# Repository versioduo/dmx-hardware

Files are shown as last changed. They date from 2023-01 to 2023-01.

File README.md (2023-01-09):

# dmx-hardware

🚥 MIDI to DMX Bridge

## Board

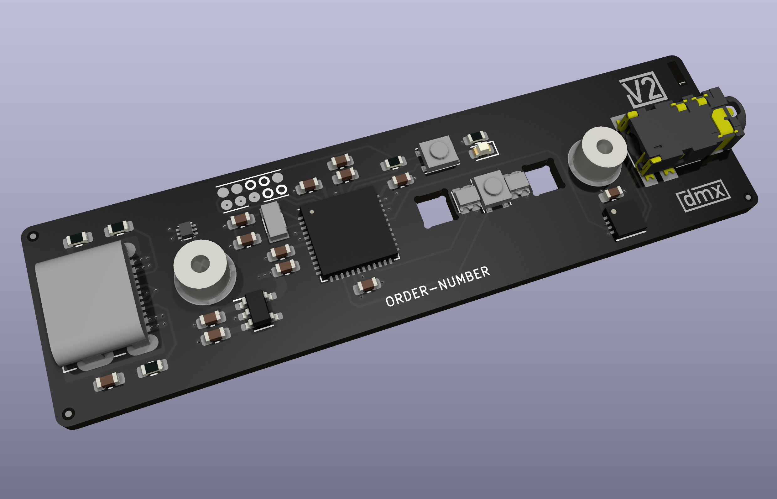
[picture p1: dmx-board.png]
board


## Schematic

[PDF](dmx.pdf)

## Bill Of Materials

[Interactive BOM](https://htmlpreview.github.io/?https://github.com/versioduo/dmx-hardware/main/dmx-bom.html)

## Software

Firmware Repository

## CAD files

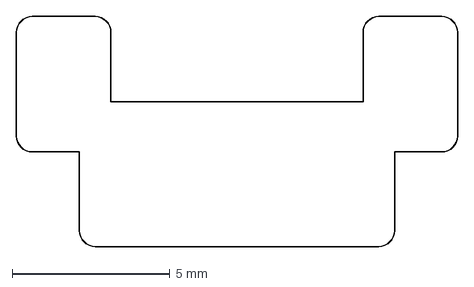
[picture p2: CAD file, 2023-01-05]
button-laser.dxf
14.0 x 7.30 mm

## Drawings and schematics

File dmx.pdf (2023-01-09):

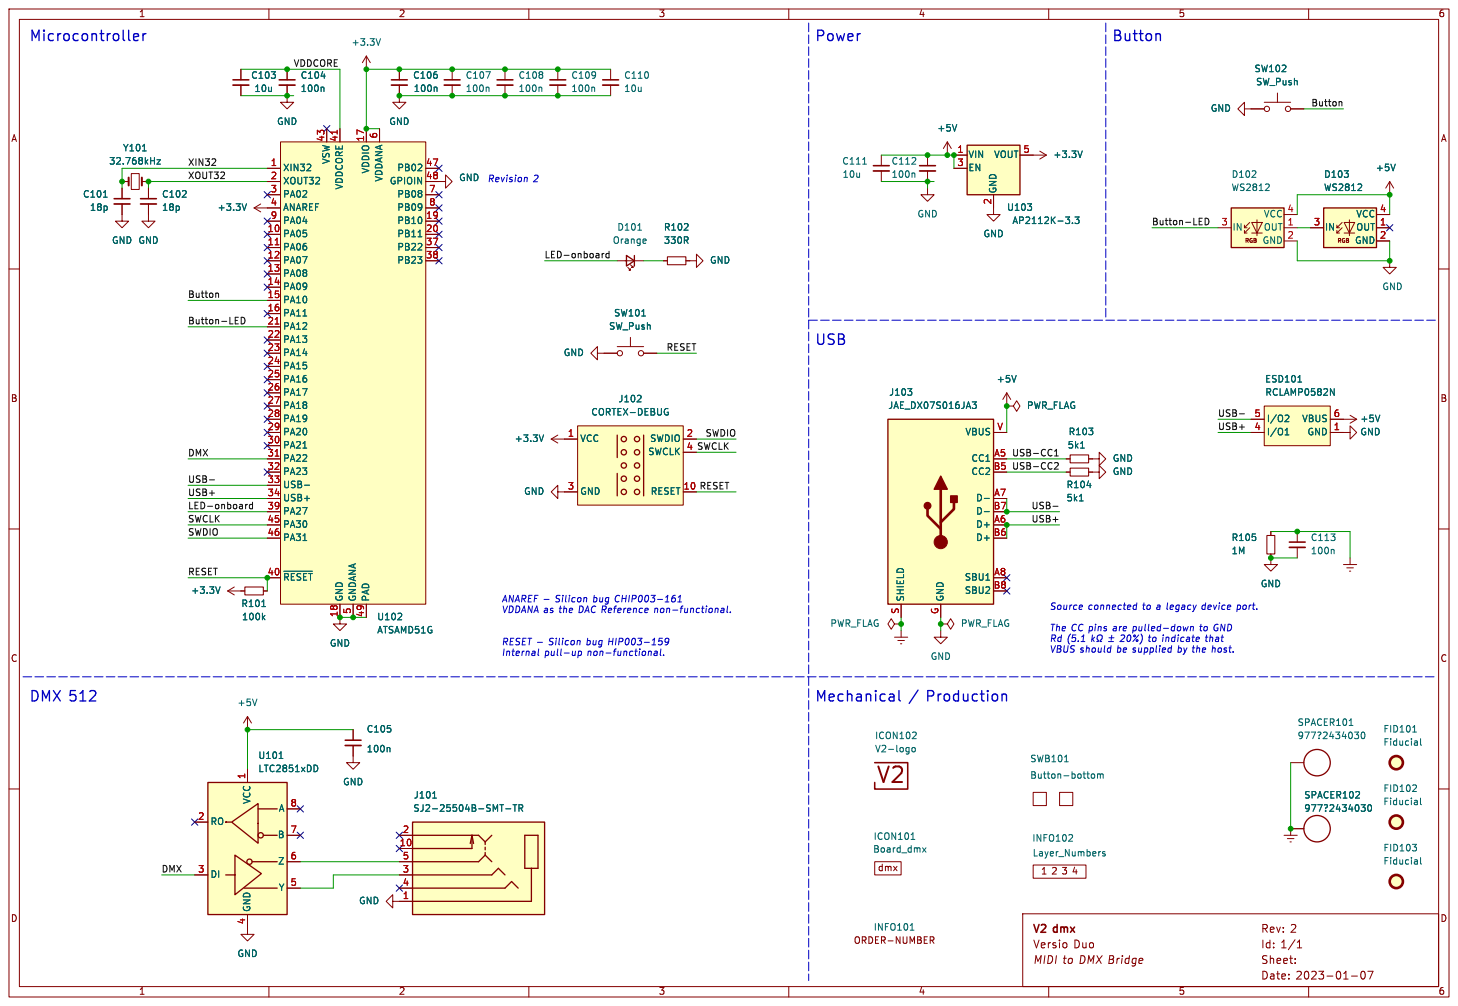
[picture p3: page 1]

The CC pins are pulled-down to GND
VBUS should be supplied by the host.

Internal pull-up non-functional.

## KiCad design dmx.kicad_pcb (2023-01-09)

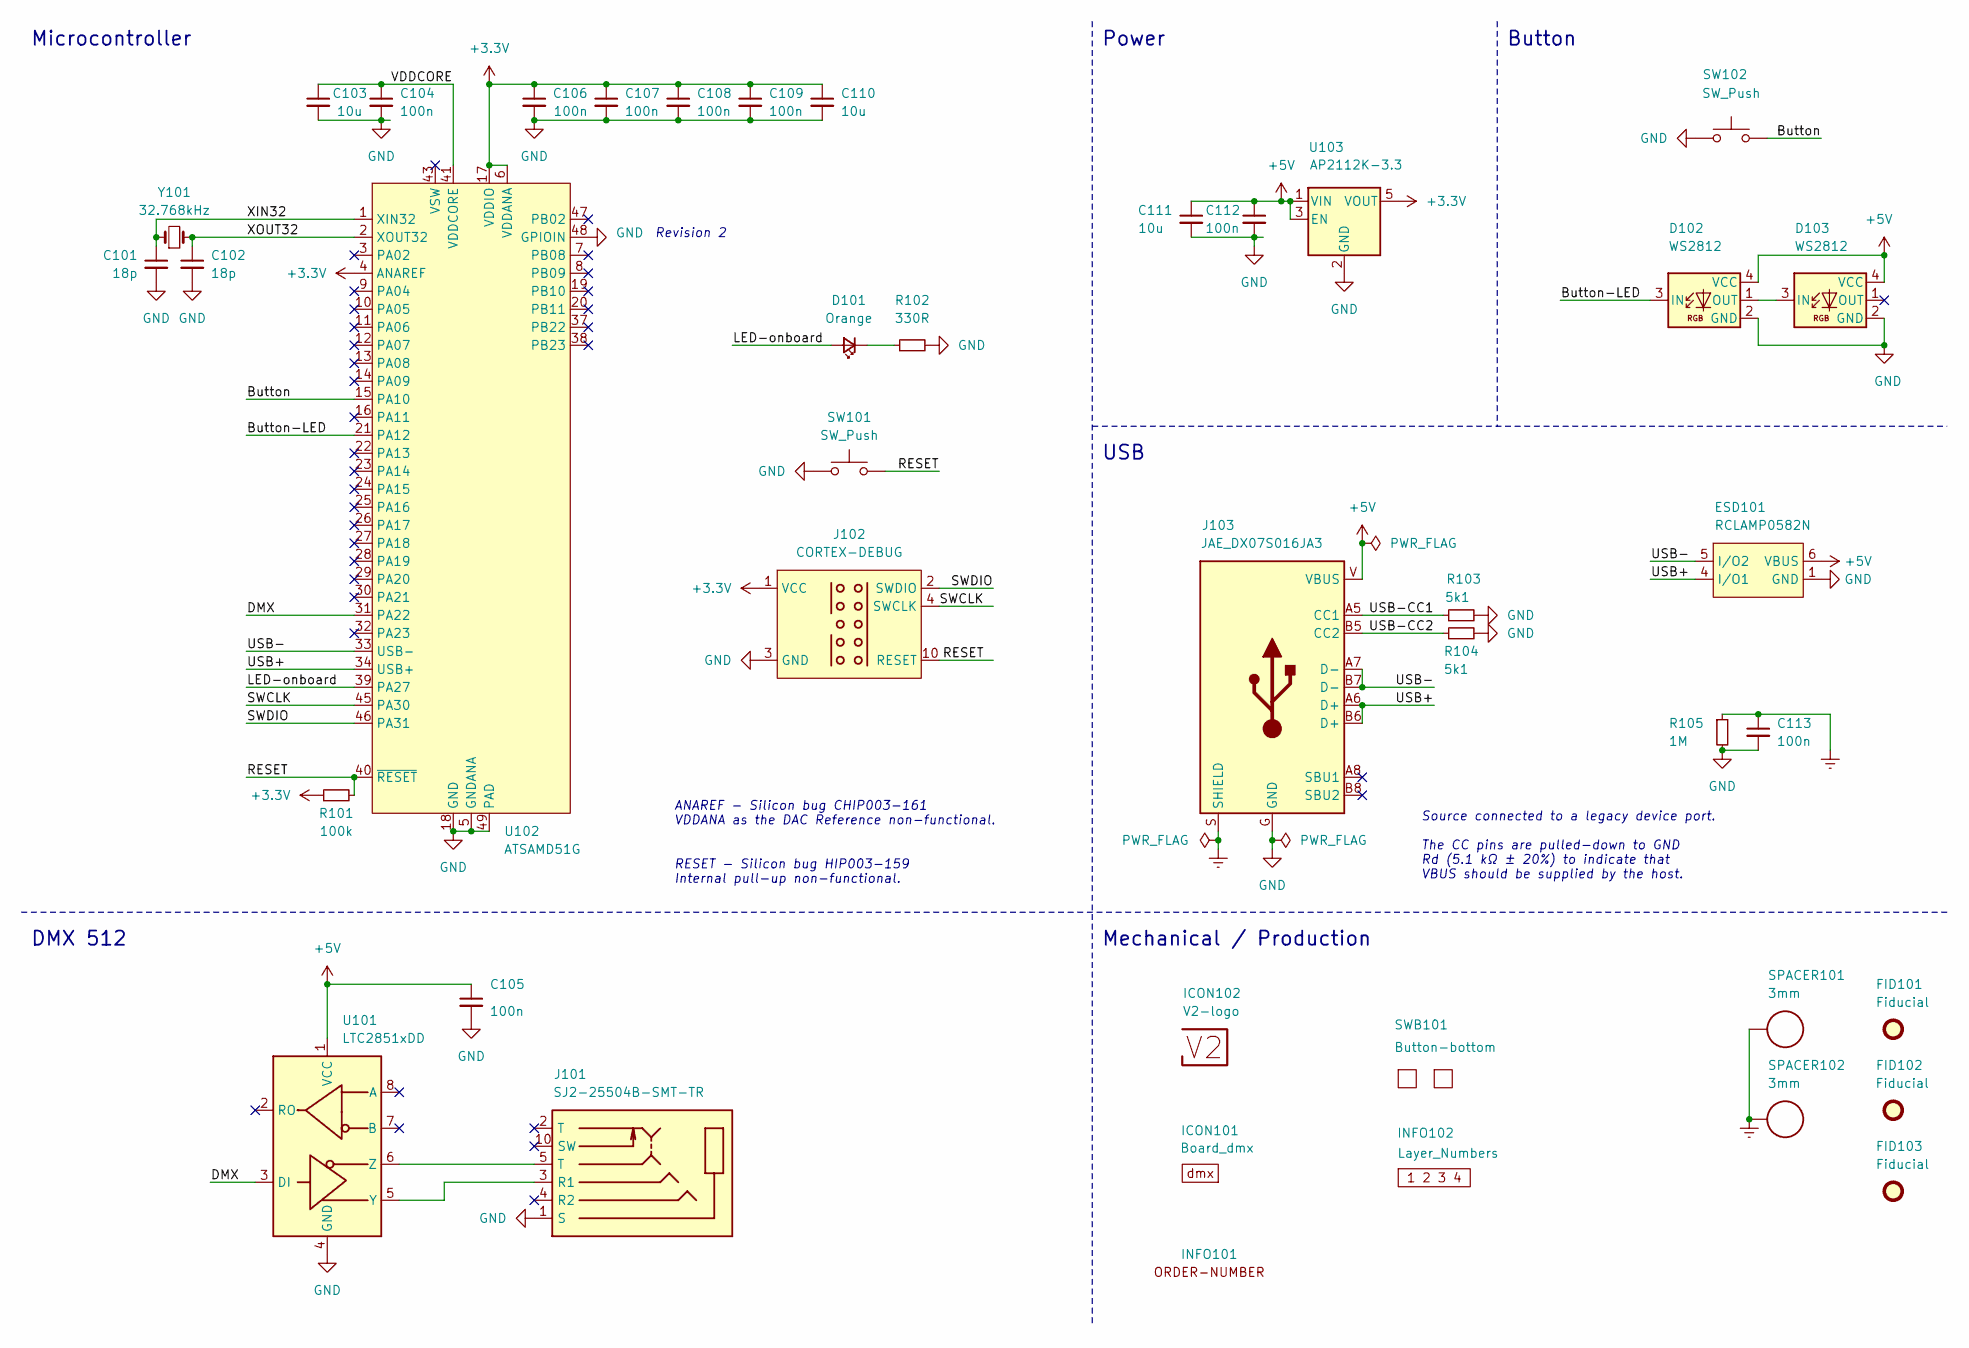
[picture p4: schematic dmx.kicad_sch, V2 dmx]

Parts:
C101, C102: 18p; C_0603_1608Metric
C103, C110, C111: 10u; C_0603_1608Metric
C104, C105, C106, C107, C108, C109, C112, C113: 100n; C_0603_1608Metric
D101: Orange; LED_0603_1608Metric
D102, D103: WS2812; WS2812-2020
ESD101: RCLAMP0582N; SLP1210N6
FID101, FID102, FID103: Fiducial; Fiducial_0.5mm_Mask1mm_Paste
ICON101: Board_dmx; Board_dmx_Small
ICON102: V2-logo; Logo_Small
INFO101: ORDER-NUMBER; Order_Number
INFO102: Layer_Numbers
J101: SJ2-25504B-SMT-TR; CUI_SJ2-25504B-SMT-TR
J102: CORTEX-DEBUG; Cortex_Debug_Pad
J103: JAE_DX07S016JA3
R101: 100k; R_0603_1608Metric
R102: 330R; R_0603_1608Metric
R103, R104: 5k1; R_0603_1608Metric
R105: 1M; R_0603_1608Metric
SPACER101, SPACER102: 3mm; 9774030243
SW101, SW102: SW_Push; SKSG
SWB101: Button-bottom; PCB_Button-bottom
U101: LTC2851xDD; DFN-8-1EP_3x3mm_P0.5mm_EP1.66x2.38mm
U102: ATSAMD51G; QFN-48-1EP_7x7mm_P0.5mm_EP5.45x5.45mm_ThermalVias
U103: AP2112K-3.3; SOT-23-5
Y101: 32.768kHz; Crystal_SMD_3215-2Pin_3.2x1.5mm

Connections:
+3.3V: C106.1, C107.1, C108.1, C109.1, C110.1, J102.1 (VCC), R101.1, U102.4 (ANAREF), U102.6 (VDDANA), U102.17 (VDDIO), U102.36 (VDDIO), U102.44 (VDDIO), U103.5 (VOUT)
+5V: C105.1, C111.1, C112.1, D102.4 (VCC), D103.4 (VCC), ESD101.6 (VBUS), J103.V (VBUS), U101.1 (VCC), U103.1 (VIN), U103.3 (EN)
/Button: SW102.2, U102.15 (PA10)
/Button-LED: D102.3 (IN), U102.21 (PA12)
/DMX: U101.3 (DI), U102.31 (PA22)
/LED-onboard: D101.2 (A), U102.39 (PA27)
/RESET: J102.10 (RESET), R101.2, SW101.2, U102.40 (~RESET)
/SWCLK: J102.4 (SWCLK), U102.45 (PA30)
/SWDIO: J102.2 (SWDIO), U102.46 (PA31)
/USB+: ESD101.4 (I/O1), J103.A6 (D+), J103.B6 (D+), U102.34 (USB+)
/USB-: ESD101.5 (I/O2), J103.A7 (D-), J103.B7 (D-), U102.33 (USB-)
/USB-CC1: J103.A5 (CC1), R103.1
/USB-CC2: J103.B5 (CC2), R104.1
/VDDCORE: C103.1, C104.1, U102.41 (VDDCORE)
/XIN32: C101.1, U102.1 (XIN32), Y101.1
/XOUT32: C102.1, U102.2 (XOUT32), Y101.2
Earth: C113.1, J103.S (SHIELD), R105.1, SPACER101.1, SPACER102.1
GND: C101.2, C102.2, C103.2, C104.2, C105.2, C106.2, C107.2, C108.2, C109.2, C110.2, C111.2, C112.2, C113.2, D102.2 (GND), D103.2 (GND), ESD101.1 (GND), J101.1 (S), J102.3 (GND), J102.5 (GND), J103.G (GND), R102.2, R103.2, R104.2, R105.2, SW101.1, SW102.1, U101.4 (GND), U101.9 (GND), U102.5 (GNDANA), U102.18 (GND), U102.35 (GND), U102.42 (GND), U102.48 (GPIOIN), U102.49 (PAD), U103.2 (GND)
unnamed: D101.1 (K), R102.1
unnamed: D102.1 (OUT), D103.3 (IN)
unnamed: J101.3 (R1), U101.5 (Y)
unnamed: J101.5 (T), U101.6 (Z)

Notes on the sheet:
 ANAREF - Silicon bug CHIP003-161 VDDANA as the DAC Reference non-functional.
RESET -  Silicon bug HIP003-159 Internal pull-up non-functional.
 Source connected to a legacy device port. The CC pins are pulled-down to GND Rd (5.1 kΩ ± 20%) to indicate that VBUS should be supplied by the host.
Button
Revision 2
Mechanical / Production
Power
Microcontroller
USB
DMX 512

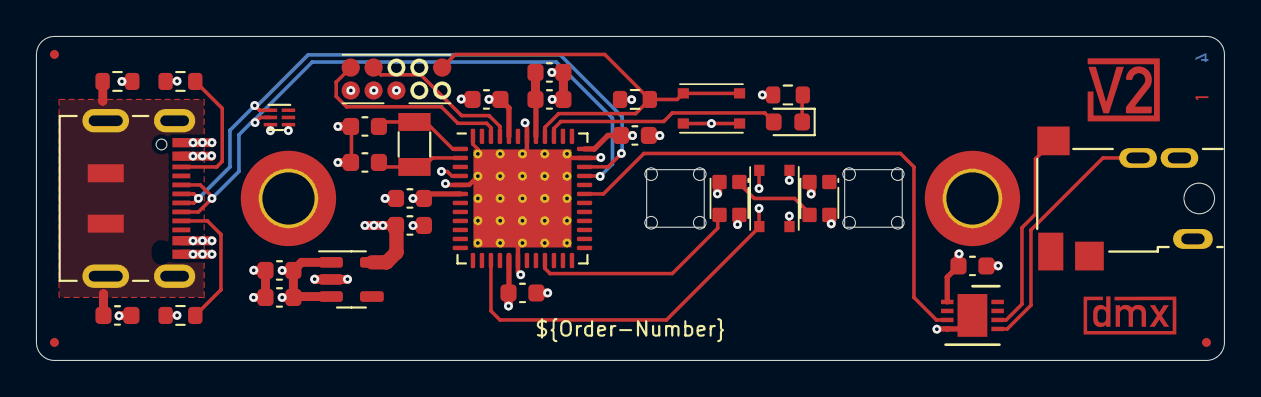
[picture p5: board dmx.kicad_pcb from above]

Board: 4 copper layers, 66.0 x 18.0 mm, 41 parts (0 on the bottom side), 22 nets.
